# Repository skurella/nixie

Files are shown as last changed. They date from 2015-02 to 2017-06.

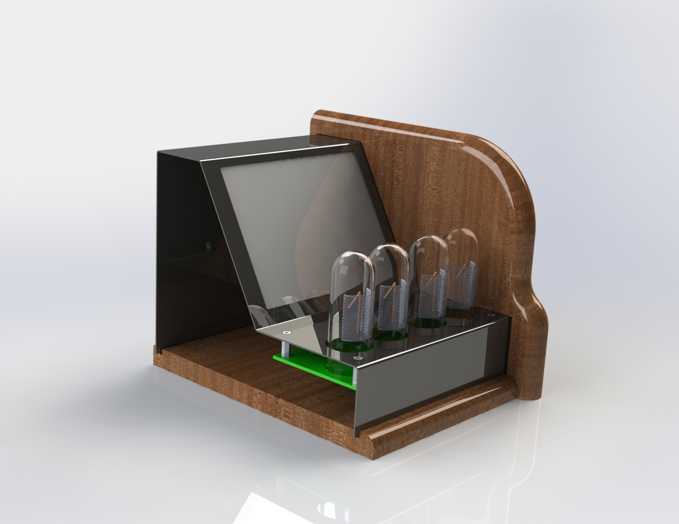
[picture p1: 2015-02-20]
mechanical/housing_render4.JPG

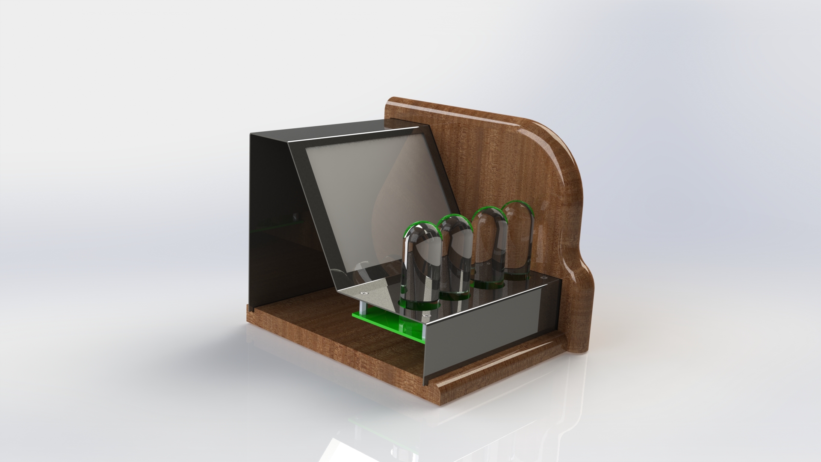
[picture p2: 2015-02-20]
mechanical/housing_render3.JPG

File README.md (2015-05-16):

# nixie
## Nixie tube

Nixie tubes were used extensivaly in 60's and 70's in various instruments to display digits and other symbols. They are cold cathode tubes made of glass with one anode (a grid) and multiple cathodes, each of which is shaped like the displayed sign.

Cold cathode means that the tube is cool during operation (usually does not exceed 40°C). However, it runs on high voltage (around 200V), so do not attempt to build this project if you don't know exactly what you are doing.

## Clock

- features four tubes to display hours and minutes
- has an alarm
- is powered by 12V DC
- easily reprogrammable with a PICkit3
- can communicate via serial
- time is battery backed

## Electronics

- Microchip PIC16F722A/723A microcontroller
- Microchip MCP7940N real-time clock/calendar
- switching HV supply
- multiplexed display: one anode pulled to HV, BCD driver pulls selected cathode to ground

## I/O

### Inputs

- rotary encoder with a momentary switch
- push-button (optional)
- anode voltage trimmer

### Outputs

- 4 nixie tubes with digits 0-9
- two LEDs in the upper left-hand corner
- buzzer connector (12V)

### Serial port

There is an optional 3-pin header with GND, TX and RX available should there be a need for interfacing with other equipment.

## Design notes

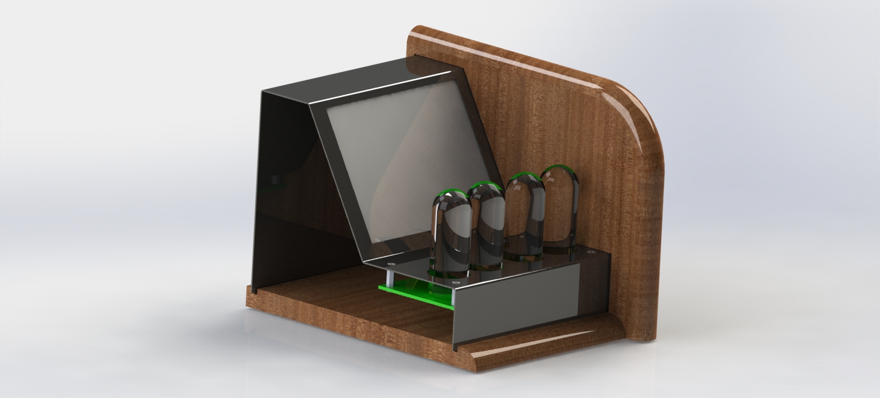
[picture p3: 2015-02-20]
mechanical/housing_render2.JPG

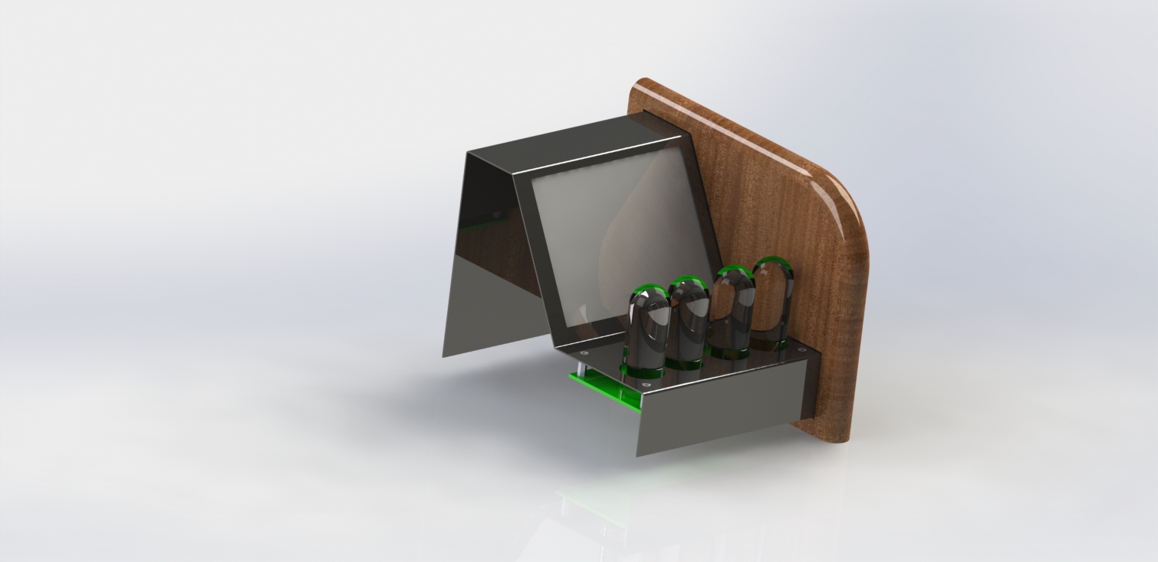
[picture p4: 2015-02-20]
mechanical/housing_render1.JPG

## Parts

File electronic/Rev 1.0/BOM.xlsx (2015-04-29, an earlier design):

Part | Package | Value | On PCB | Manufacturer | Quantity | Farnell | RS | Link | Unit price | Total price
R1-4 | SMD 0805 | 390K | 4 |  | 10 | 2332106 |  | http://uk.farnell.com/te-connectivity/crgh0805f390k/resistor-power-390k-0-33w-1-0805/dp/2332106 | 0.0196 | 0.0784
R5-8 | SMD 0805 | 51K | 4 |  | 10 | 2323854 |  | http://uk.farnell.com/panasonic-electronic-components/erj6geyj513v/resistor-thick-film-51kohm-5-0805/dp/2323854 | 0.009 | 0.036
R9, R11 | SMD 0805 | 10k | 2 |  | 10 | 1612522 |  | http://uk.farnell.com/bourns/cr0805-fx-1002elf/resistor-10k-0-125w-1/dp/1612522 | 0.029 | 0.058
R10 | SMD 0805 | 47k | 1 |  | 10 | 2333525 |  | http://uk.farnell.com/bourns/cr0805-fx-4702elf/resistor-thick-film-47kohm-1-0805/dp/2333525 | 0.0281 | 0.0281
R12, R13 | SMD 0805 | 2k2 | 2 |  | 10 | 2333608 |  | http://uk.farnell.com/bourns/cr0805-jw-222elf/resistor-thick-film-2-2kohm-5/dp/2333608 | 0.0319 | 0.0638
R14 | SMD 0805 | 1k | 1 |  | 10 | 1652936 |  | http://uk.farnell.com/vishay-draloric/crcw08051k00fkta/thick-film-chip-resistor/dp/1652936 | 0.02 | 0.02
R15 | SMD 0805 | 680k | 1 |  | 10 | 2303859 |  | http://uk.farnell.com/panasonic-electronic-components/erj6enf6803v/res-thick-film-680k-125mw-1-0805/dp/2303859 | 0.013 | 0.013
R16 | SMD 0805 | 330R | 1 |  | 10 | 2333593 |  | http://uk.farnell.com/bourns/cr0805-jw-331elf/resistor-thick-film-330-ohm-5/dp/2333593 | 0.0304 | 0.0304
R17 | SMD 0805 | 3k3 | 1 |  | 10 | 2303604 |  | http://uk.farnell.com/panasonic-electronic-components/erj6enf3301v/res-thick-film-3k3-125mw-1-0805/dp/2303604 | 0.016 | 0.016
C1-2 | SMD 0805 | 18pF | 2 |  | 10 | 1759194 |  | http://uk.farnell.com/multicomp/mc0805n180j500ct/cap-mlcc-c0g-np0-18pf-50v-0805/dp/1759194 | 0.0192 | 0.0384
C3-4, 7-8, 10, 13 | SMD 0805 | 100nF | 4 |  | 10 | 2407344 |  | http://uk.farnell.com/vishay/vj0805y104kxacw1bc/cap-mlcc-x7r-0-1uf-50v-0805/dp/2407344 | 0.01 | 0.04
C5-6 | SMD radial 4mm | 10uF | 2 |  | 10 | 2326109 |  | http://uk.farnell.com/panasonic-electronic-components/eee1ca100ar/cap-alu-elec-10uf-16v-smd/dp/2326109 | 0.173 | 0.346
C9 | SMD 0805 | 100pF | 1 |  | 10 | 2210931 |  | http://uk.farnell.com/tdk/cga4c2c0g2a101j060aa/cap-mlcc-c0g-np0-100pf-100v-0805/dp/2210931 | 0.0493 | 0.0493
C11 |  | 1000uF | 1 |  | 5 | 2065974 |  | http://uk.farnell.com/panasonic-electronic-components/eeeft1c102ap/cap-alu-elec-1000uf-16v-smd/dp/2065974 | 0.832 | 0.832
C12 |  | 4.7uF | 1 |  | 3 | 2346642 |  | http://uk.farnell.com/rubycon/400px4r7mefcta8x11-5/cap-alu-elec-4-7uf-400v-rad/dp/2346642 | 0.302 | 0.302
C14 | SMD 0805 | 1nF | 1 |  | 5 | 9695192 |  | http://uk.farnell.com/panasonic-electronic-components/echu1h102gx5/cap-film-pps-1nf-50v-smd/dp/9695192 | 0.333 | 0.333
L1 |  | 330uH | 1 |  | 2 | 2457912 |  | http://uk.farnell.com/coilcraft/rfc1010b-334ke/inductor-power-330uh-1-5a-10/dp/2457912 | 0.46 | 0.46
Q1-4 | SOT23 | MMBTA92 | 4 |  | 10 | 2114881 |  | http://uk.farnell.com/nxp/mmbta92/trans-pnp-300v-100ma-sot23/dp/2114881 | 0.0867 | 0.3468
Q5-8 | SOT23 | MMBTA42 | 4 |  | 10 | 2114871 |  | http://uk.farnell.com/nxp/mmbta42/trans-npn-300v-100ma-sot23/dp/2114871 | 0.0857 | 0.3428
Q9 | TO-220 | IRF840 | 1 |  | 3 |  | 542-9440 | http://uk.rs-online.com/web/p/mosfet-transistors/5429440/ | 1.2 | 1.2
D1 | DO-214AC | Schottky | 1 |  | 10 |  | 670-8817 | http://uk.rs-online.com/web/p/rectifier-schottky-diodes/6708817/ | 0.162 | 0.162
D2 | TO-220 | BYV29-400 | 1 |  | 3 | 1081351 |  | http://uk.farnell.com/nxp/byv29-400/diode-ultrafast-9a/dp/1081351 | 0.707 | 0.707
U1 | SOIC16 | CD4028B | 1 | TI | 2 | 2342417 |  | http://uk.farnell.com/texas-instruments/cd4028bm96/ic-bcd-to-decimal-decoder-soic/dp/2342417 | 0.093 | 0.093
U2-3 | SOIC16 | SN75468 | 2 | TI | 4 | 9593004 |  | http://uk.farnell.com/texas-instruments/sn75468d/transistor-array-75468-soic16/dp/9593004 | 0.422 | 0.844
U4 | SOT23 | LM3840IM3-5.0 | 1 |  | 2 | 1476698 |  | http://uk.farnell.com/taiwan-semiconductor/ts78l05cx-rf/reg-3-terminal-100ma-smd-sot-23/dp/1476698 | 0.365 | 0.365
U5 | SOIC28 | PIC16F722A-I/SO | 1 | TI | 2 | 1814931 |  | http://uk.farnell.com/microchip/pic16f723a-i-so/mcu-8bit-pic16-20mhz-soic-28/dp/1814931 | 0.89 | 0.89
U6 | SOIC8 | MCP7940N-I/SN | 1 | TI | 2 | 2361122 |  | http://uk.farnell.com/microchip/mcp7940n-i-sn/rtcc-gp-i2c-64b-sram-8soic/dp/2361122 | 0.715 | 0.715
U7 | SOIC8 | MC34063ADR | 1 | TI | 3 | 1053582 |  | http://uk.farnell.com/texas-instruments/mc34063ade4/dc-dc-controller-smd-34063-soic8/dp/1053582 | 0.56 | 0.56
BT1 |  | HU2032-LF | 1 | Renata | 2 | 1319749 |  | http://uk.farnell.com/renata/hu2032-lf/holder-battery-tht-cr2032/dp/1319749 | 0.818 | 0.818
P1 | terminal block | 1776275-2 | 1 | TE | 2 | 1098611 |  | http://uk.farnell.com/te-connectivity/1776275-2/terminal-block-wire-to-brd-2pos/dp/1098611 | 0.24 | 0.24
X1 | 3.2mm x 1.5mm | 32.768kHz, 9pF | 1 | Abracon | 2 | 2101346 |  | http://uk.farnell.com/abracon/abs07-32-768khz-9-t/crystal-32-768khz-9pf-smd/dp/2101346 | 1.11 | 1.11
VR1 |  | 2k2 | 1 |  | 2 | 1141662 |  | http://uk.farnell.com/vishay-sfernice/t7yb222mb40/trimmer-2k2/dp/1141662 | 1.17 | 1.17
V1-4 | B13D | LC-531 | 4 | Dolam | N/A |  |  |  |  | 0
EN1 |  | PEC12R-2220F-S0024 | 1 | Bourns | 2 |  | 789-9602 | http://uk.rs-online.com/web/p/mechanical-rotary-encoders/7899602/ | 0.77 | 0.77
 |  |  |  |  |  |  |  |  |  | 13.078

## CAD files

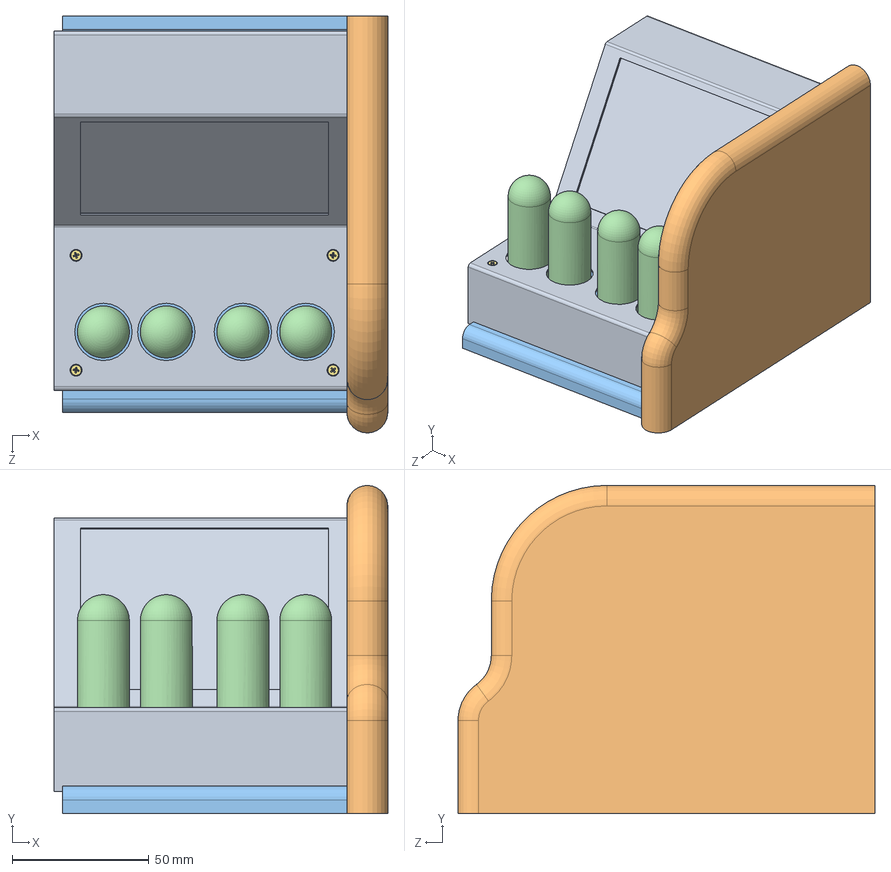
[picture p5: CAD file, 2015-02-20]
mechanical/Housing.SLDASM
122.0 x 120.0 x 152.5 mm
Cover
Right panel
Driver PCB
Nixie tube x 4
Nixie anode x 4
Nixie cathode 1 x 4
flat head screw_am x 4
pan cross head_am x 4
Display
Distance x 4
Bottom panel

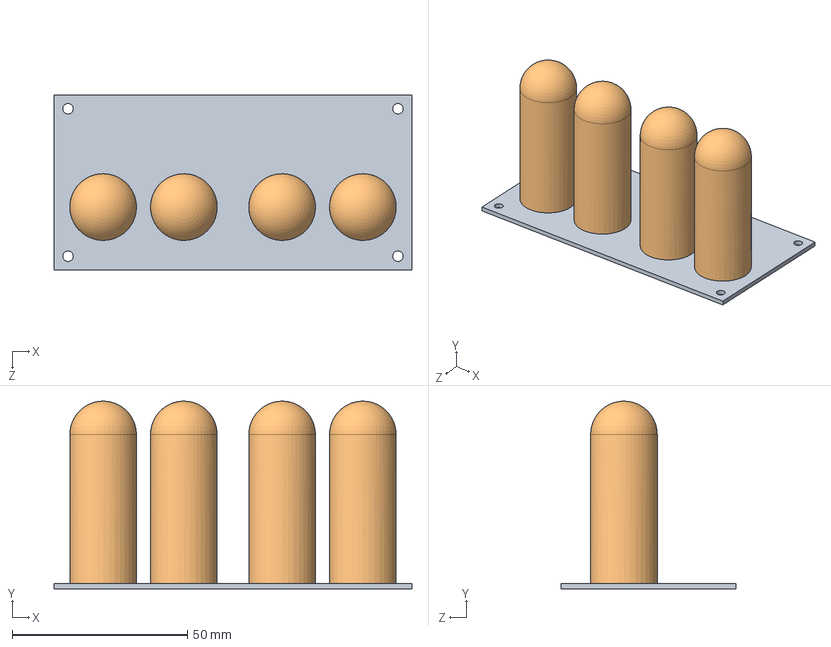
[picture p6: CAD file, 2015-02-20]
mechanical/Driver with tubes.SLDASM
102.0 x 53.5 x 50.0 mm
Driver PCB
Nixie tube x 4
Nixie anode x 4
Nixie cathode 1 x 4

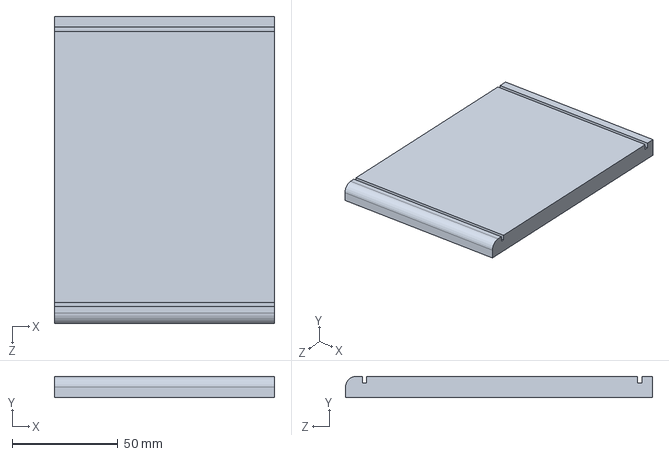
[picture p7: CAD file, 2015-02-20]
mechanical/Bottom panel.SLDPRT
104.0 x 10.0 x 145.0 mm

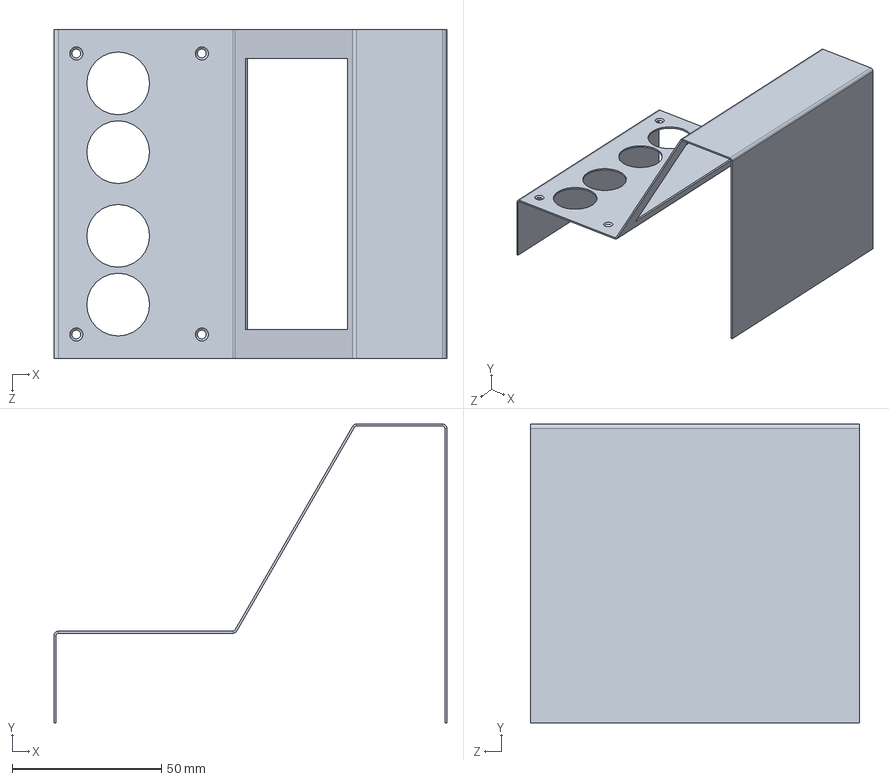
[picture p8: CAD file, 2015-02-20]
mechanical/Cover.sldprt
131.5 x 100.0 x 110.0 mm

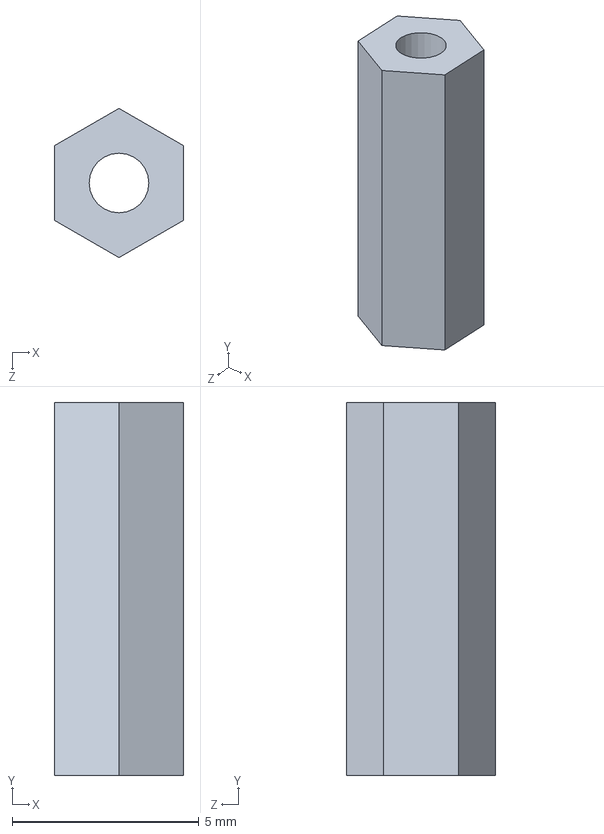
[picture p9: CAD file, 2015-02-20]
mechanical/Distance.SLDPRT
3.46 x 10.0 x 4.00 mm

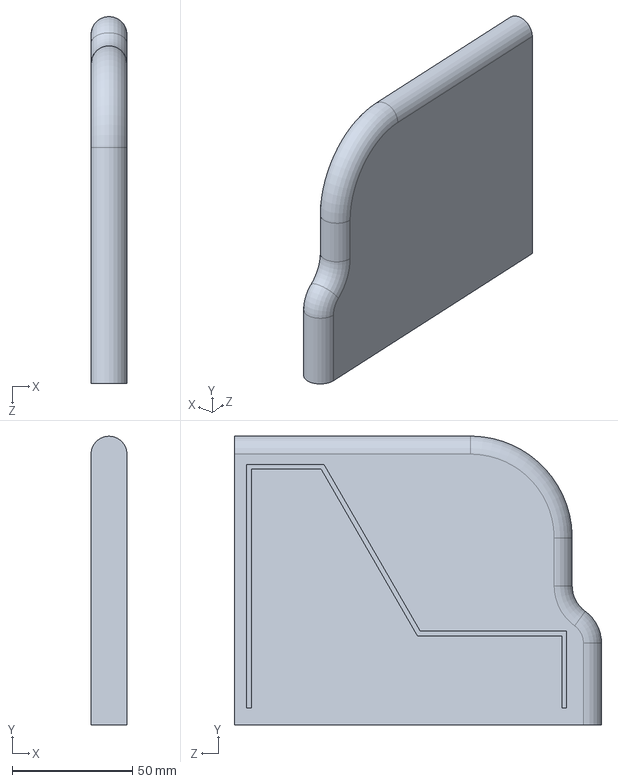
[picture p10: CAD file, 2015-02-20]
mechanical/Right panel.SLDPRT
15.0 x 120.0 x 152.5 mm

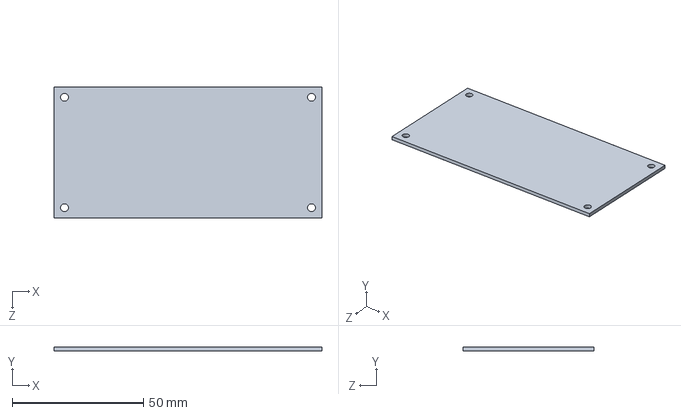
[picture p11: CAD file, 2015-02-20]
mechanical/Driver PCB.SLDPRT
102.0 x 1.50 x 50.0 mm

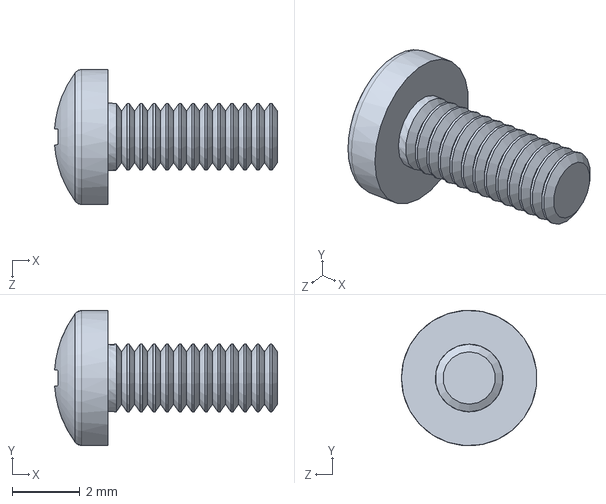
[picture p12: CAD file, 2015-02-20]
mechanical/B18.6.7M - M2 x 0.4 x 5 Type I Cross Recessed PHMS --5S.sldprt
6.58 x 4.00 x 3.99 mm

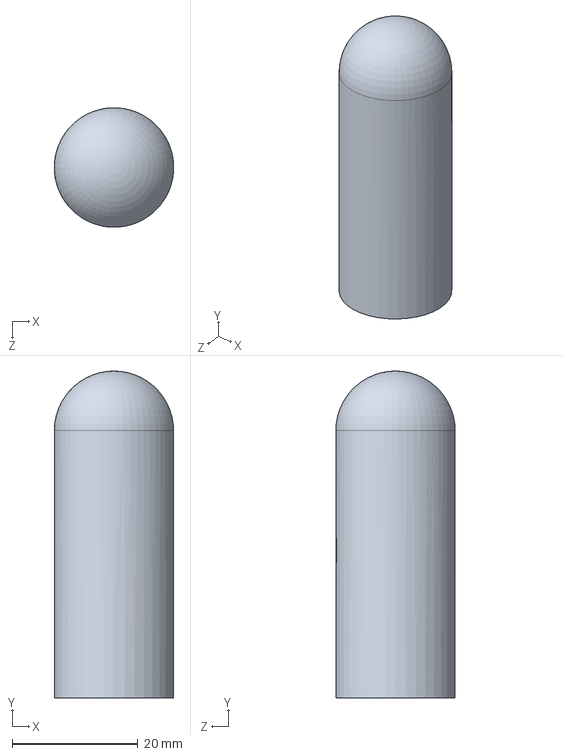
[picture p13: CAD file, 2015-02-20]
mechanical/Nixie tube.SLDPRT
19.0 x 52.0 x 19.0 mm

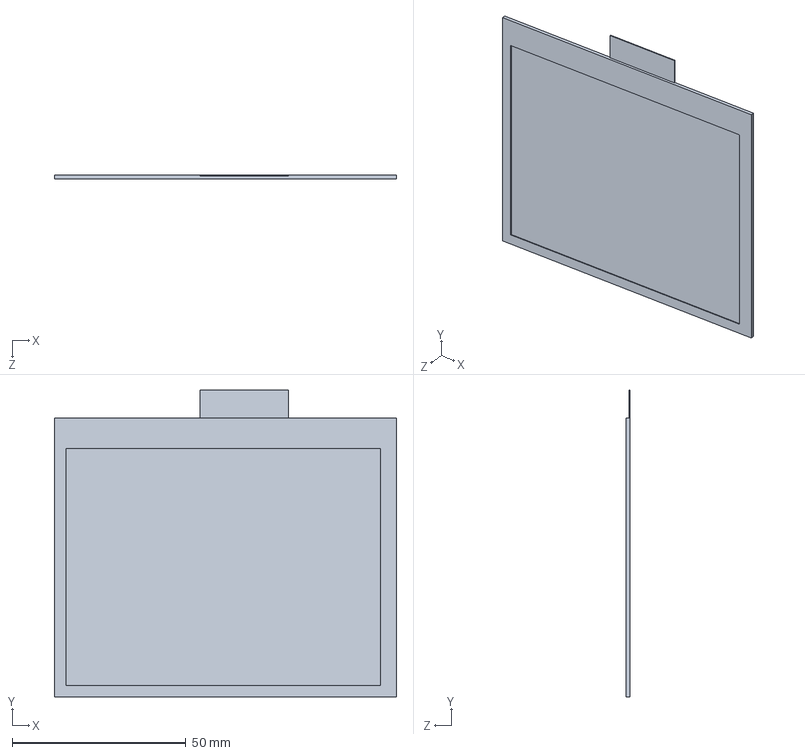
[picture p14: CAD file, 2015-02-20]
mechanical/Display.SLDPRT
98.5 x 88.4 x 1.20 mm

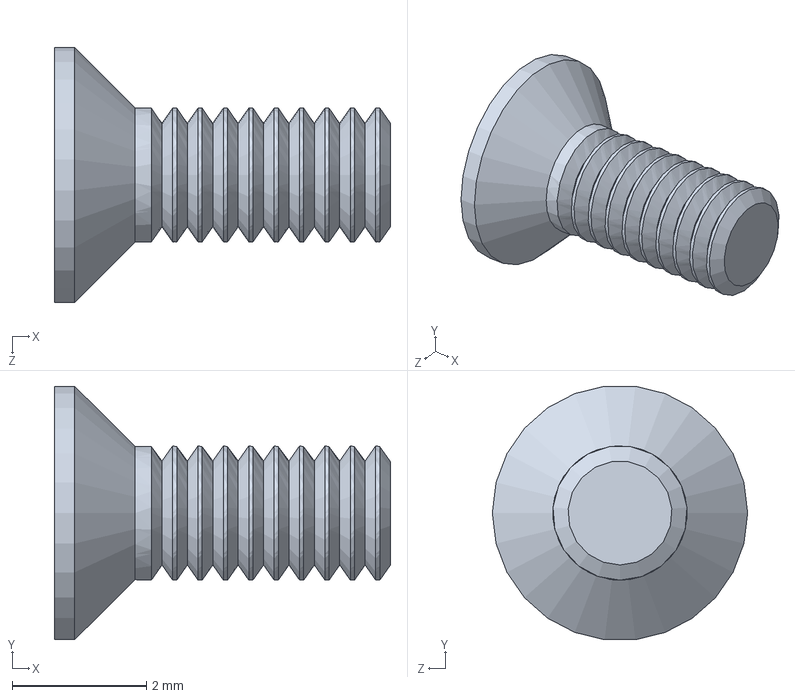
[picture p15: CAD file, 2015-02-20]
mechanical/B18.6.7M - M2 x 0.4 x 5 Type I Cross Recessed FHMS --5S.sldprt
5.00 x 3.77 x 3.80 mm

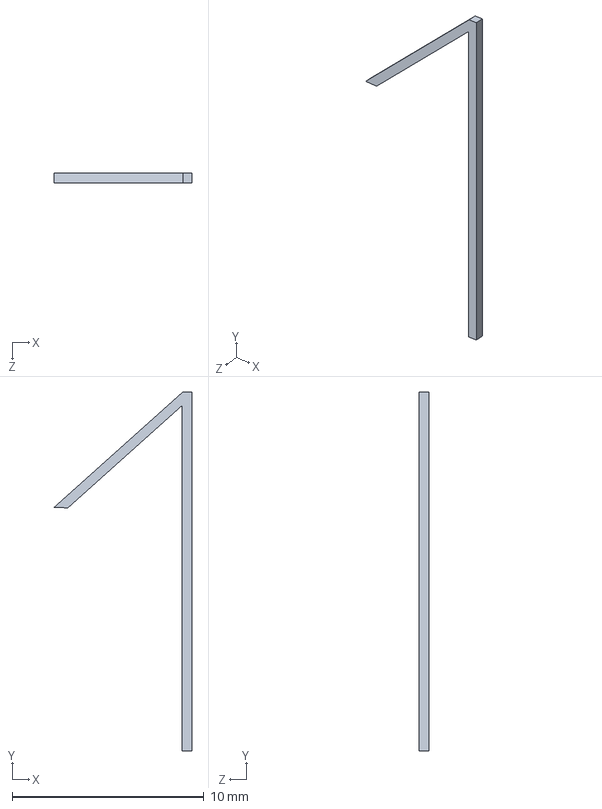
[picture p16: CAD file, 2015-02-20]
mechanical/Nixie cathode 1.SLDPRT
7.17 x 18.7 x 0.5 mm

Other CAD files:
mechanical/Display.SLDDRW

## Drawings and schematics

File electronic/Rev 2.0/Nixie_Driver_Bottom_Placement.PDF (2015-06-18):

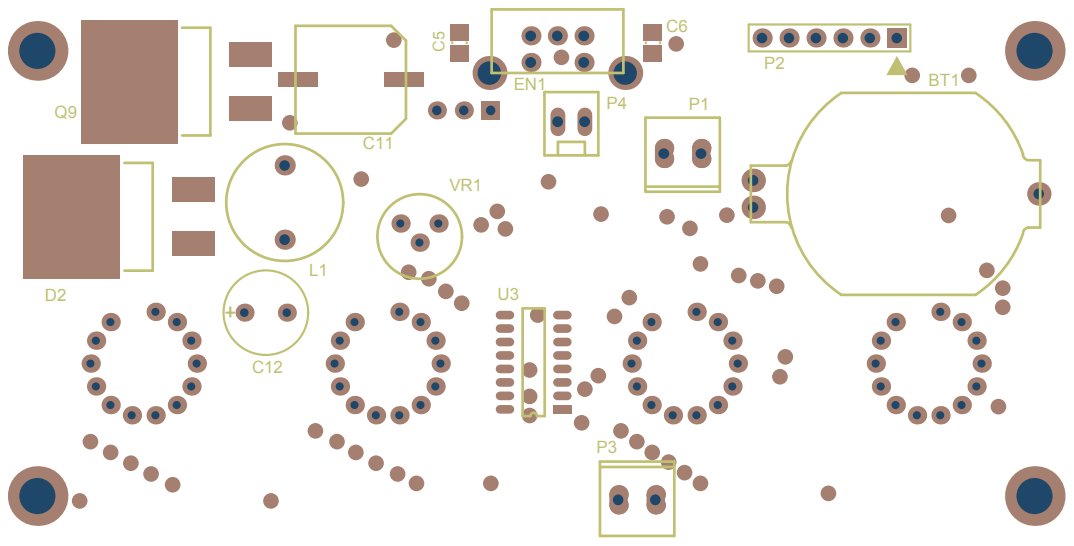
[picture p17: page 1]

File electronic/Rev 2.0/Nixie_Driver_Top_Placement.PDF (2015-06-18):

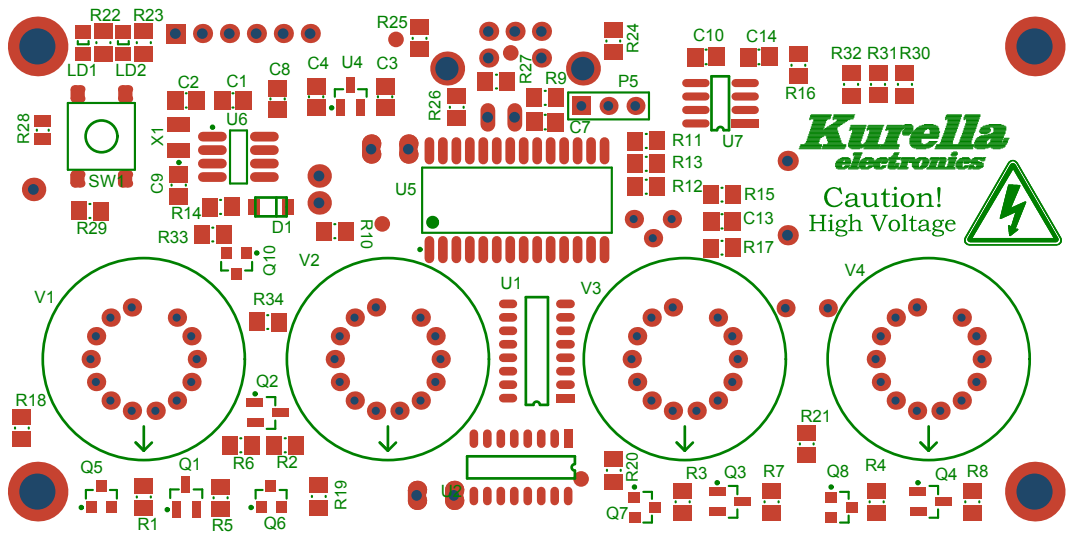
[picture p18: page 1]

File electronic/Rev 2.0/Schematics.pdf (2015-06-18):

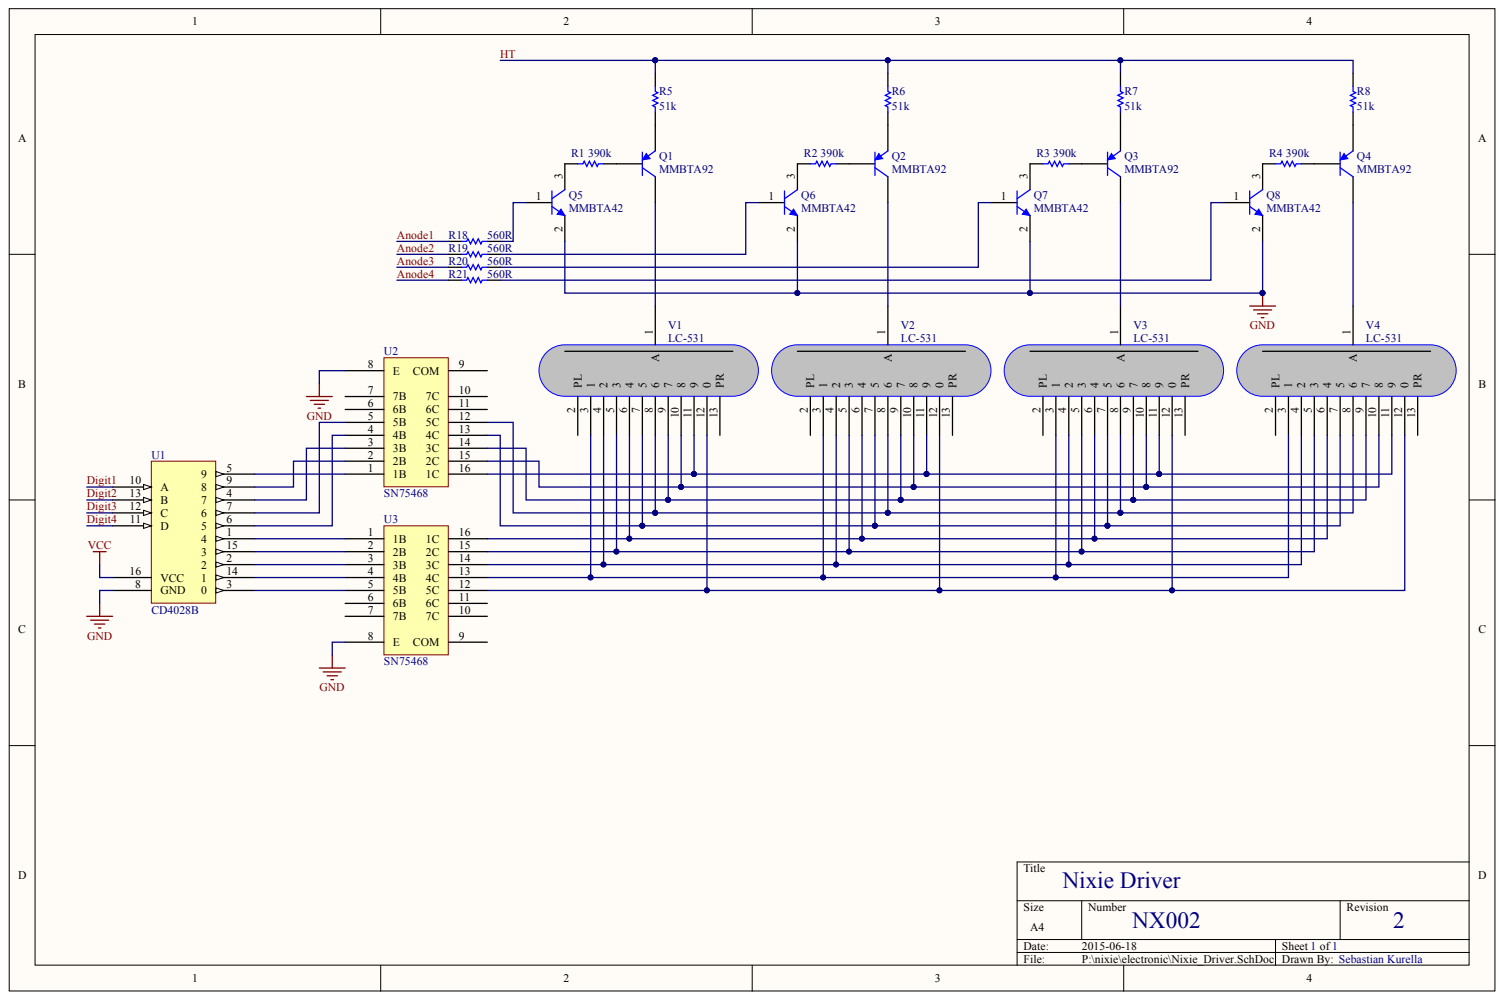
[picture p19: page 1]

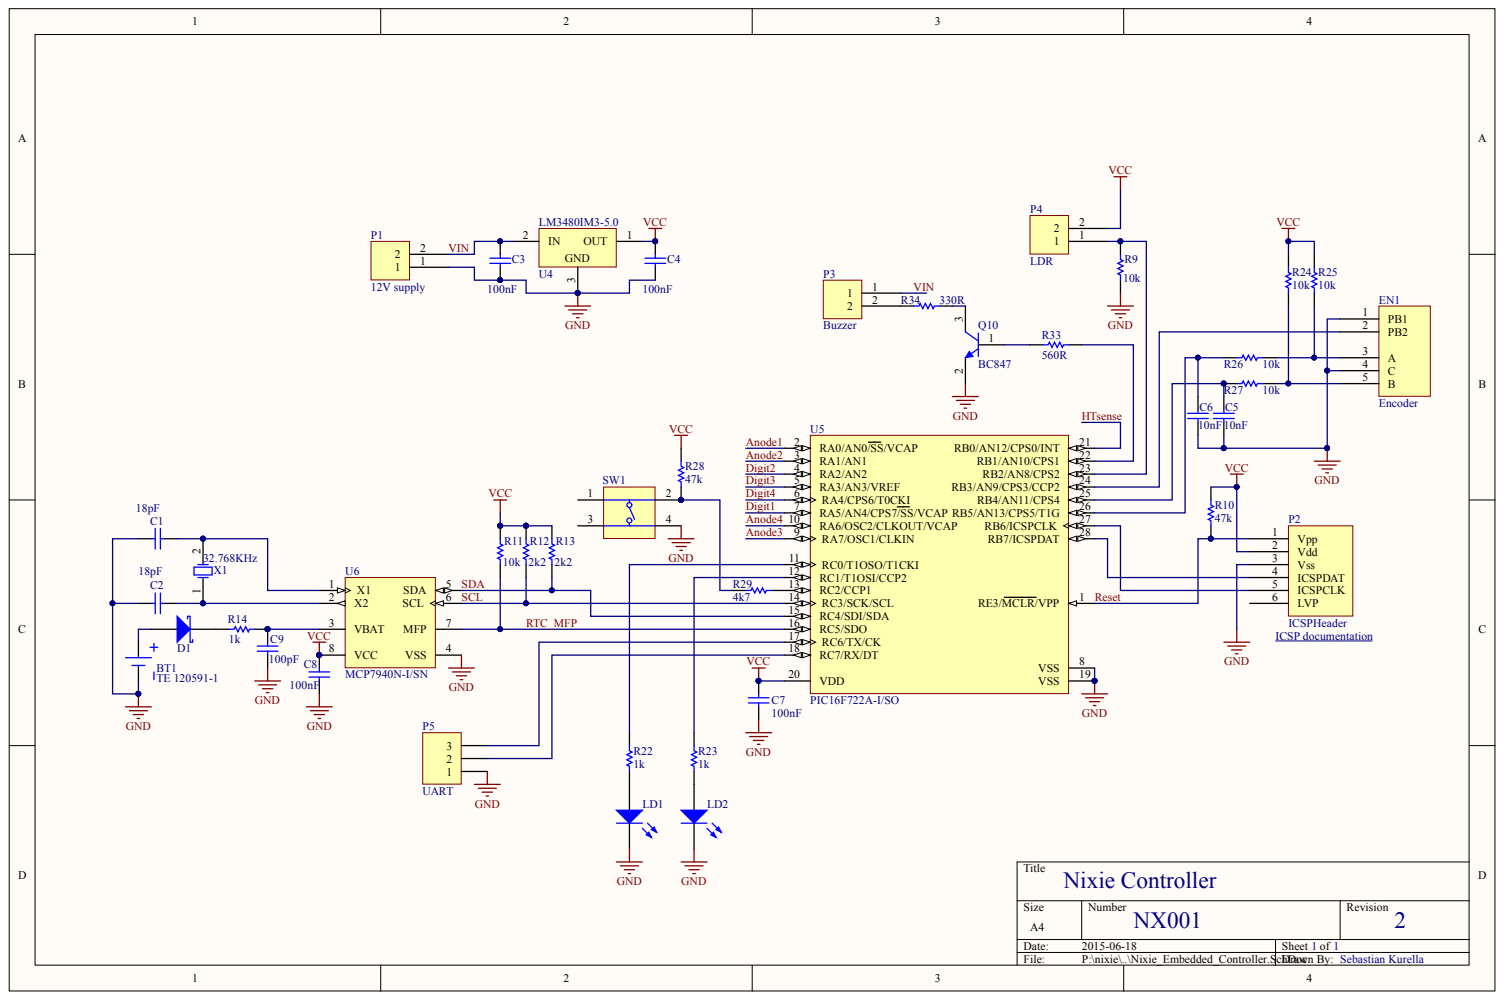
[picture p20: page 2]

2 | 6 | 4k7 | RC3/SCK/SCL 14 | Reset | 6

7 | | RC4/SDI/SDA 15

RTC_MF P | | RC5/SDO 16

RC6/TX/CK 17
RC7/RX/DT 18

VCC

P:\nixie\..\Nixie_Embedded_Controller.SchDoc Drawn By:

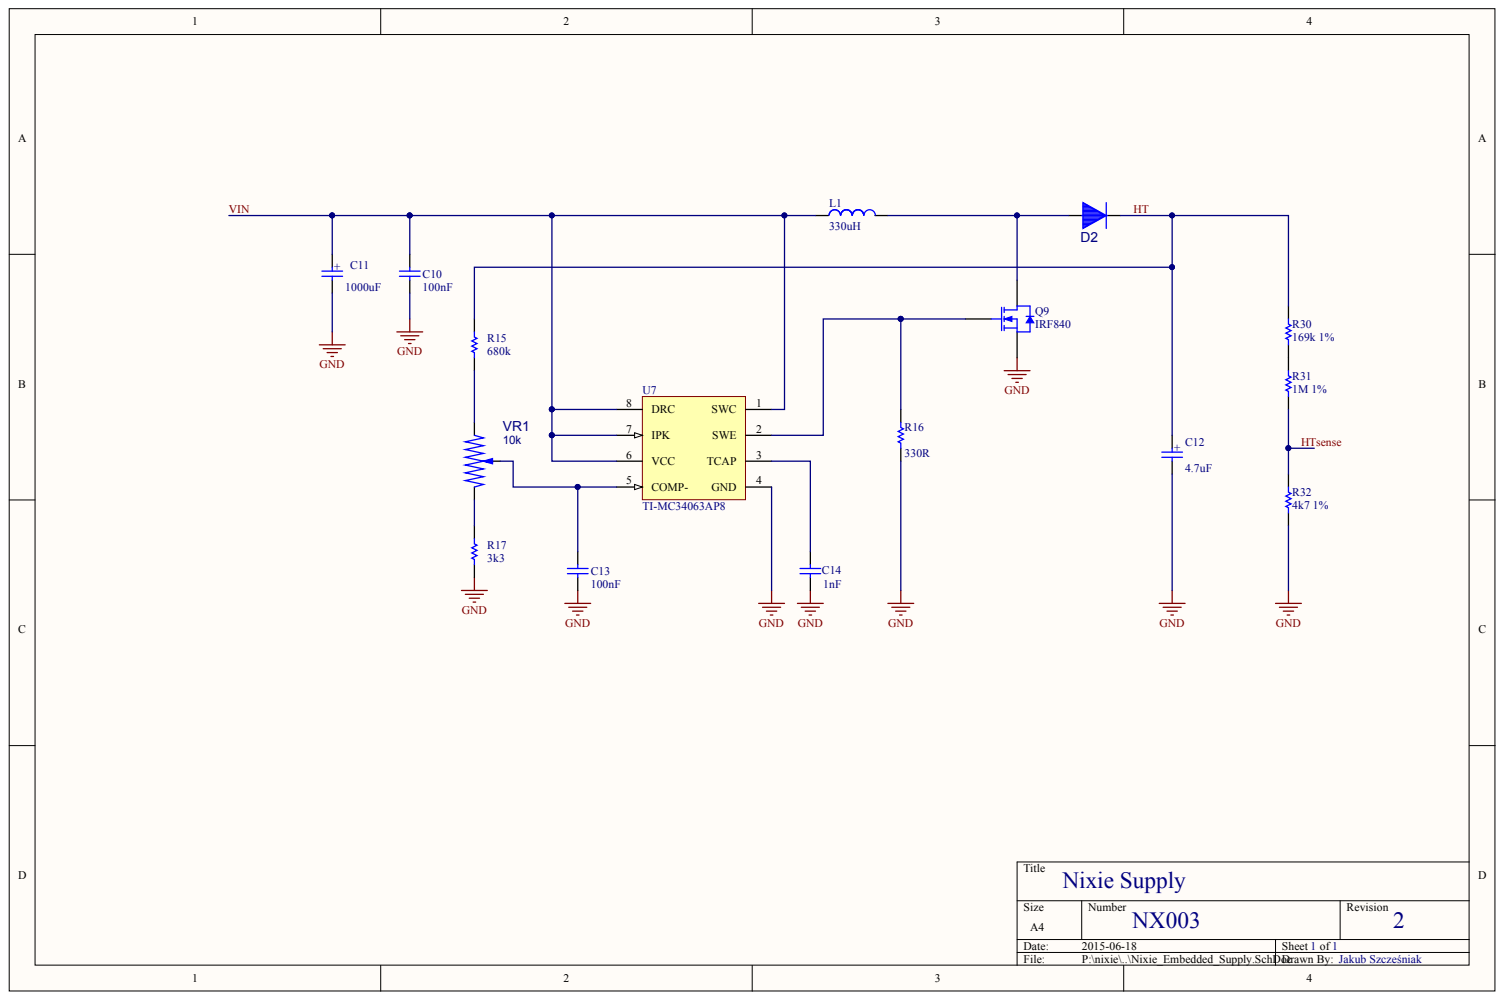
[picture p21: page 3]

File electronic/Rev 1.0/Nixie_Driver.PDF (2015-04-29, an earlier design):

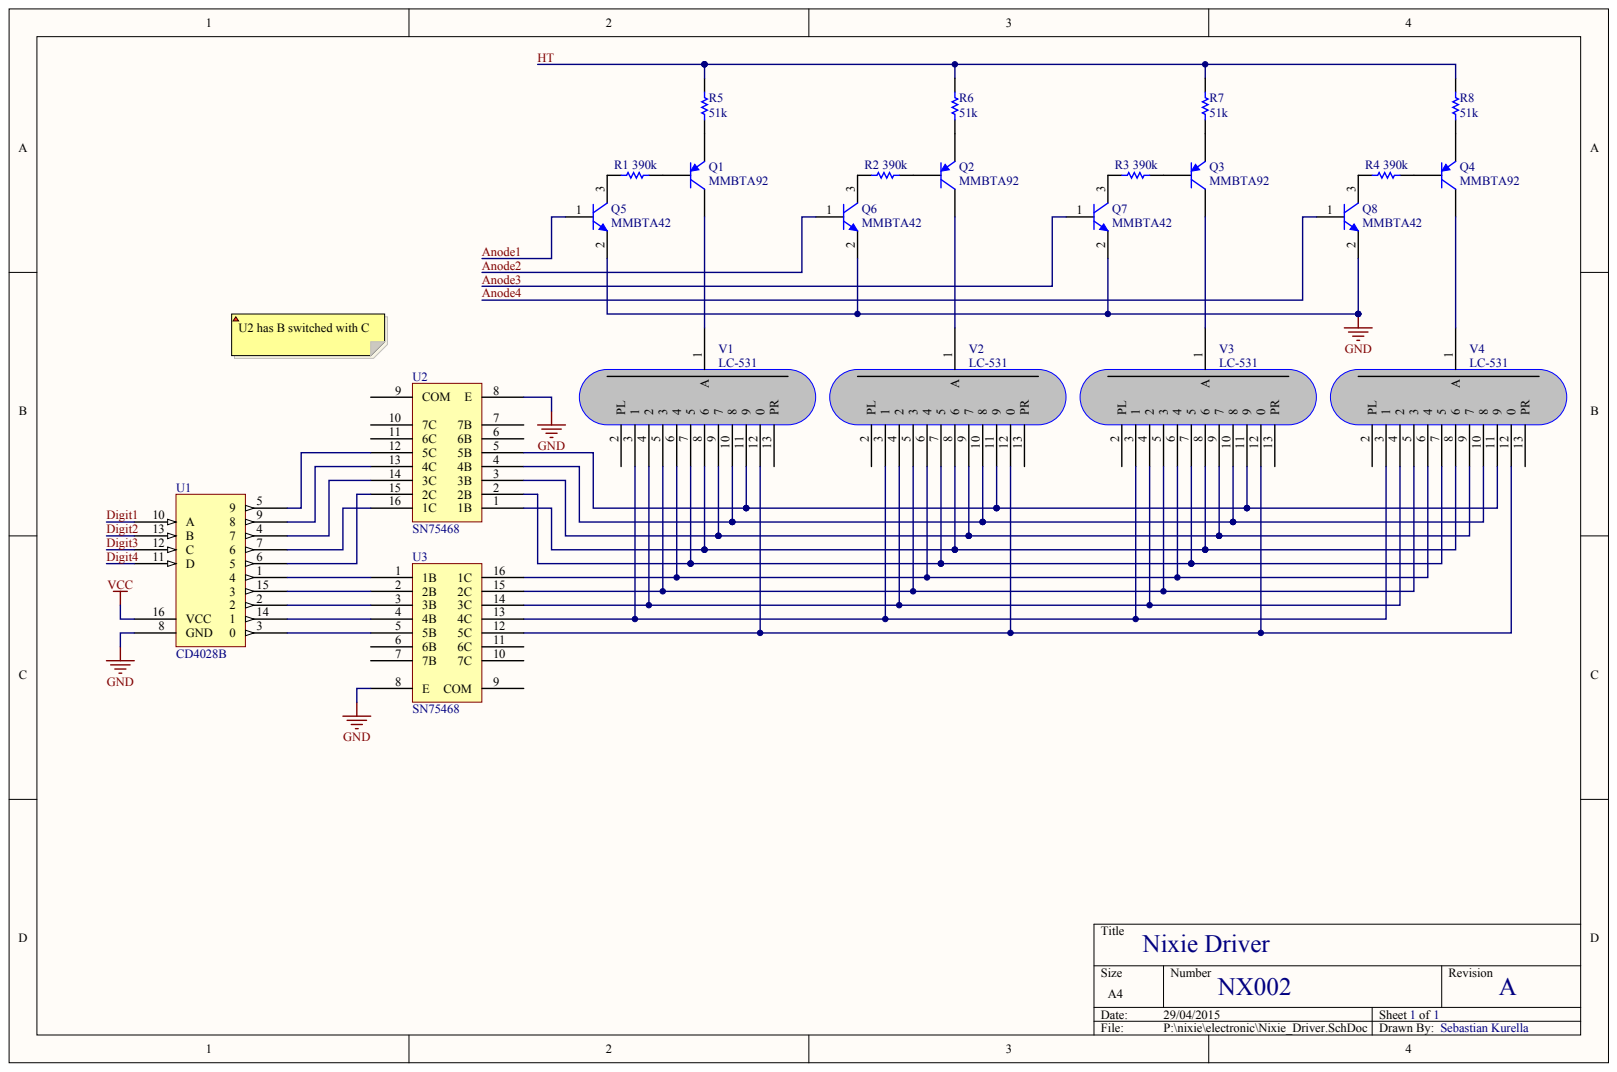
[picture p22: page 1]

Anode3
Anode4

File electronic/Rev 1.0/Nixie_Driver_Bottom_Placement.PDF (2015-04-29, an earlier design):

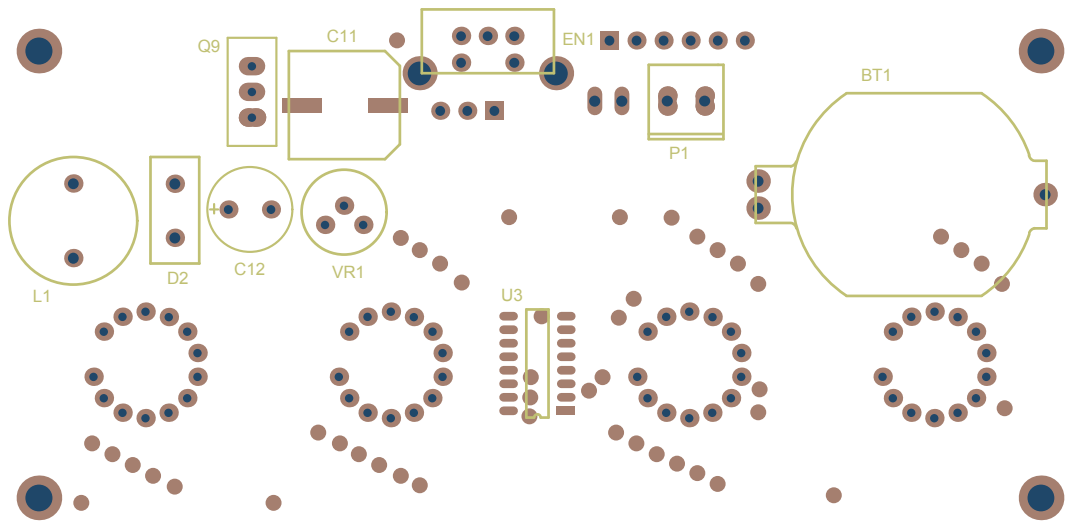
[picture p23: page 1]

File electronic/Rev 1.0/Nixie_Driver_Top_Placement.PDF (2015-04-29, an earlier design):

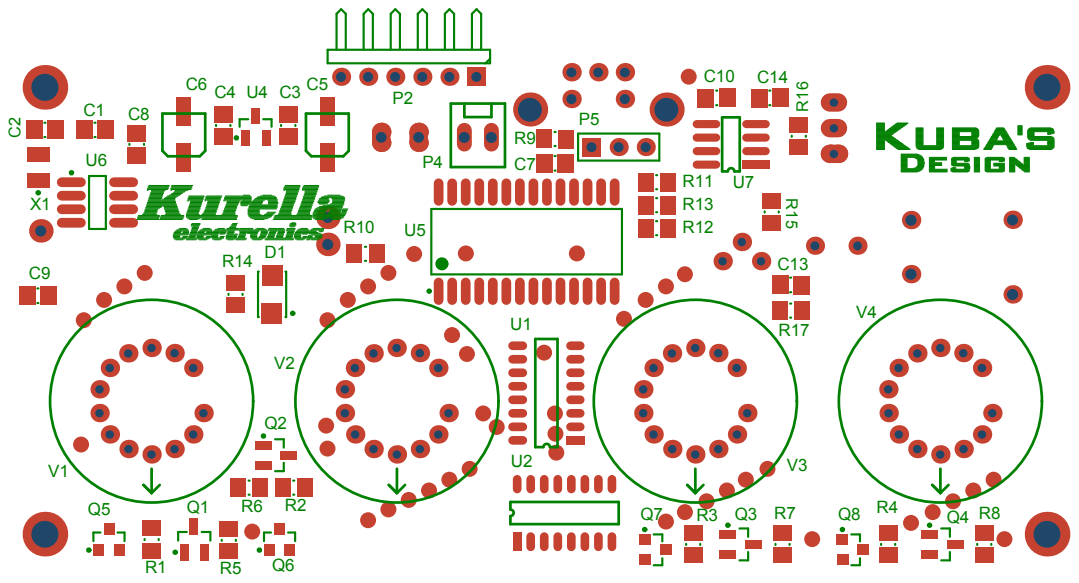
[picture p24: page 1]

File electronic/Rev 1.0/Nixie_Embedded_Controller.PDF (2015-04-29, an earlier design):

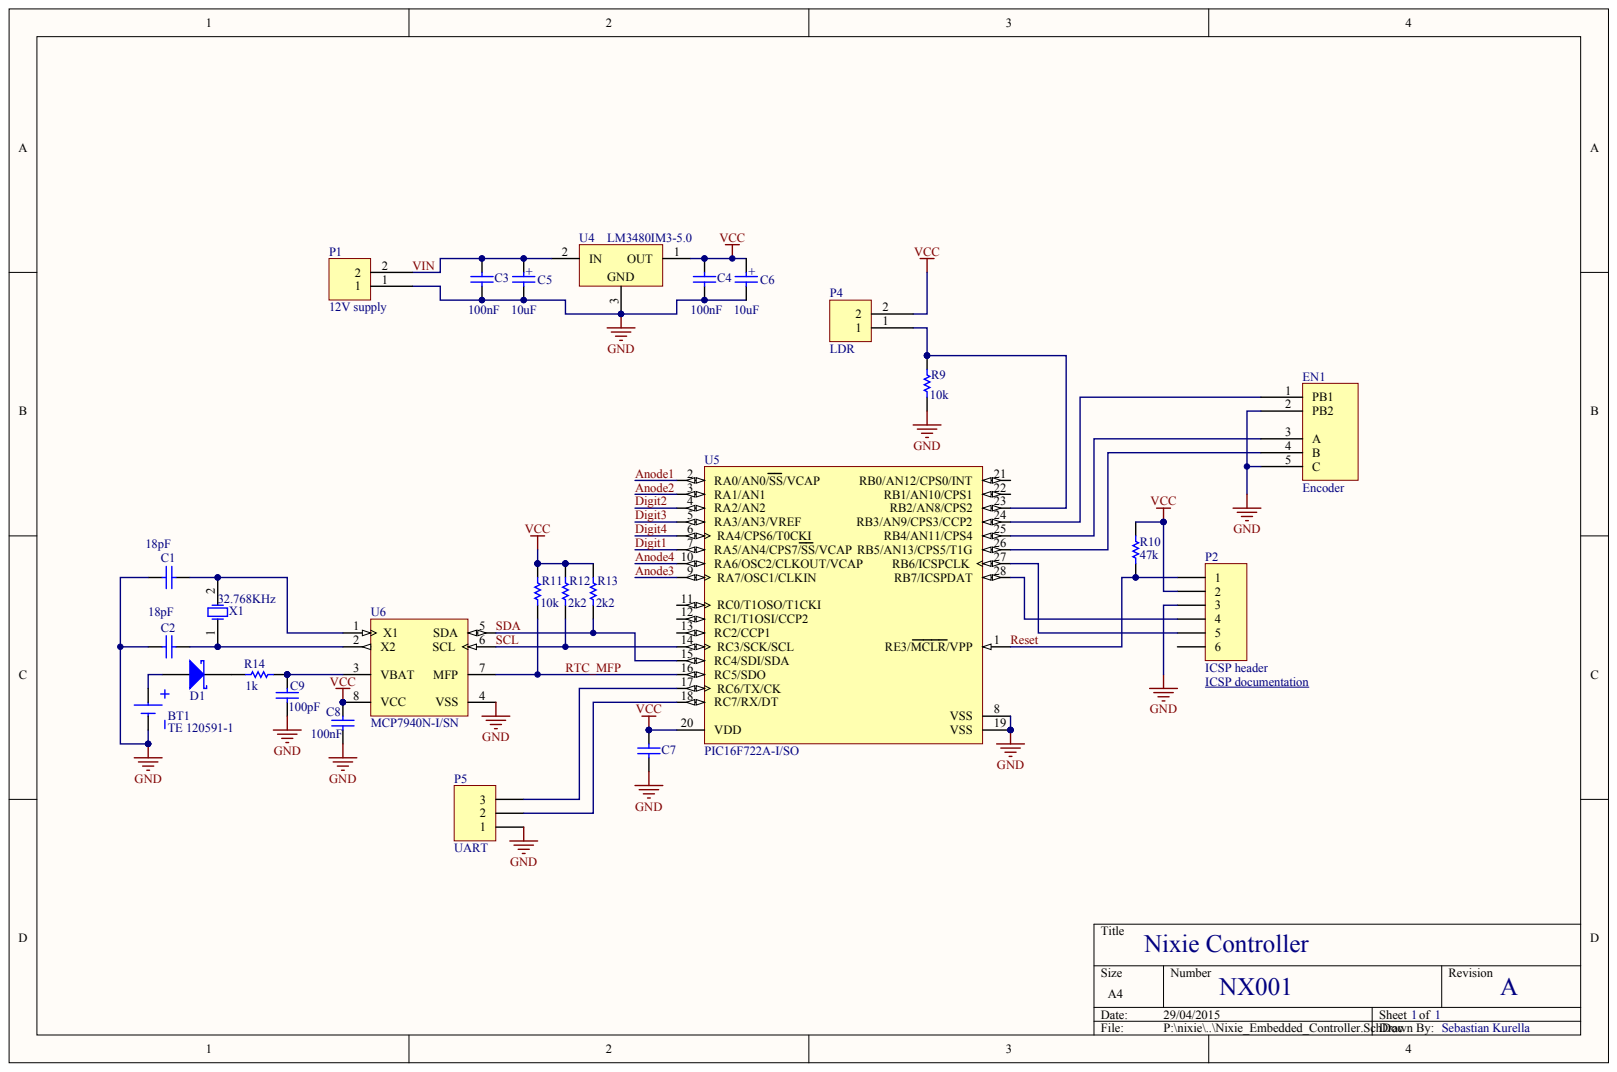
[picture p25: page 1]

2 | 6 | SCL | RC3/SCK/SCL 14 | Reset

7 | | RC4/SDI/SDA 15

VCC

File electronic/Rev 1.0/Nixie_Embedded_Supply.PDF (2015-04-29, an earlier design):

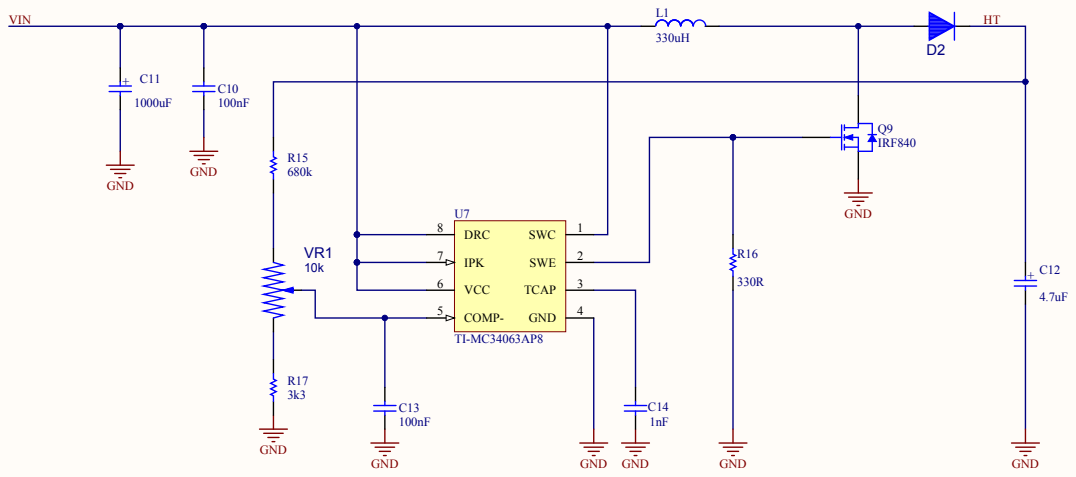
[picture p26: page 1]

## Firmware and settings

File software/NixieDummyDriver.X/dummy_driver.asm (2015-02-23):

;/////////////////////////////////////////////////////;
;/ Nixie tube clock driver dummy - simulates nixies  /;
;/ To be used with University of Manchester IO Board /;
;/ Author: Sebastian Kurella                         /;
;/                                                   /;
;/ PB2 displays hours, PB1 displays minutes          /;
;/ Low nibble of SW1 is simulated 74141 input        /;
;/ High nibble of SW1 is simulated 'tube select'     /;
;/////////////////////////////////////////////////////;



        processor   18F8722
        #include    <P18F8722.INC>
        config      OSC=HS, WDT=OFF, LVP=OFF
        radix       decimal

        CBLOCK	0x80

        HoursT      ; tens digit of current hour
        HoursU      ; units digit of current hour
        MinutesT    ; tens digit of current minute
        MinutesU    ; units digit of current minute

        DispView    ; 0 - hours, 1 - minutes

        LDispValue  ; digit to be displayed on right display
        RDispValue  ; digit to be displayed on right display

        WREG_TEMP	; variables used for context saving
        STATUS_TEMP
        BSR_TEMP

        ENDC

; reset vector - this is the entry point of the program
        ORG     0x0000
        goto    Init

; high priority interrupt vector
        ORG     0x0008
        ; high-p int code goes here
        retfie  FAST

; low priority interrupt vector
        ORG     0x0018
        goto    LowInt



; BCDTable is a lookup table which converts BCD to RF config
; in order to display this digit on 7-segment display

BCDTable    sublw   9           ; check if number is within BCD range
            btfss   STATUS, 0   ; if WREG was > 9, it's invalid
            retlw   B'11111011'
            sublw   9           ; return WREG to original state

            movf    PCL, F      ; update PC registers
            rlncf   WREG, W     ; multiply by 2 to get the correct offset
            addwf   PCL         ; Add offset to force jump into table
            retlw   B'10000100' ; '0'
            retlw   B'11110101' ; '1'
            retlw   B'01001100' ; '2'
            retlw   B'01100100' ; '3'
            retlw   B'00110101' ; '4'
            retlw   B'00100110' ; '5'
            retlw   B'00000110' ; '6'
            retlw   B'11110100' ; '7'
            retlw   B'00000100' ; '8'
            retlw   B'00100100' ; '9'





; initialize the microcontroller

Init    bcf     TRISH, 0        ; set RH0 as output - Q1 transistor
        bcf     TRISH, 1        ; set RH1 as output - Q2 transistor
        bcf     LATH, 0         ; pull RH0 value low - enable U1
        bsf     LATH, 1         ; pull RH1 value high - disable U2

        movlw   B'11111111'     ; set RF output values - all segments off
        movwf   LATF
        movlw   0               ; set RF as output
        movwf   TRISF

        bsf     TRISJ, 5        ; set RJ5 as input - PB1
        bsf     TRISB, 0        ; set RB0 as input - PB2

        movlw   B'00111100'     ; set RC2,3,4,5 as inputs - SW1H
        iorwf   TRISC
        movlw   B'11110000'     ; set RH4,5,6,7 as inputs - SW1L
        iorwf   TRISH
        movlw   B'00000011'     ; set RH4-7 as digital I/O
        iorwf   ADCON1

; set up initial time value
        movlw   1
        movwf   HoursT
        movlw   2
        movwf   HoursU
        movlw   3
        movwf   MinutesT
        movlw   4
        movwf   MinutesU

; initially display hours
        CALL    DispH

; set up Timer0
; display switch frequency: (10 Mhz / 4) / 64 / 2^8 = 152.6 Hz
        movlw   B'01000101'     ; Timer off, 8bit, internal clock, prescaler 1:64
        movwf   T0CON
        bsf     INTCON, TMR0IE  ; Enable overflow interrupt
        bcf     INTCON2, TMR0IP ; Low interrupt priority

        bsf     RCON, IPEN      ; Enable interrupt priority
        bsf     INTCON, GIE     ; Enable high-priority interrupts
        bsf     INTCON, PEIE    ; Enable low-priority interrupts
        bsf     T0CON, TMR0ON   ; Start Timer0


; main loop
; continuously monitor push-buttons and toggle switches

MLoop
        btfss   PORTB, 0        ; show hours if PB2 is pressed
        CALL    DispH
        btfss   PORTJ, 5        ; show minures if PB1 is pressed
        CALL    DispM

        movf    PORTH, W        ; read SW1H
        andlw   B'11110000'
        bz MLoop                ; return if none is selected

        rrncf   PORTC, W        ; read SW1L value
        rrncf   WREG
        andlw   B'00001111'

        btfsc   PORTH, 7        ; set tens of hours if SW1a is on
        movwf   HoursT
        btfsc   PORTH, 6        ; set units of hours if SW1b is on
        movwf   HoursU
        btfsc   PORTH, 5        ; set tens of minutes if SW1c is on
        movwf   MinutesT
        btfsc   PORTH, 4        ; set units of minutes if SW1d is on
        movwf   MinutesU

        CALL    DRefr

        bra     MLoop           ; execute main loop forever




; low priority interrupt saves and restores working registers
; because FAST stack is used by high priority interrupts

LowInt  movff   STATUS, STATUS_TEMP	;save STATUS register
        movff   WREG, WREG_TEMP		;save working register
        movff   BSR, BSR_TEMP		;save BSR register

        btfss   INTCON, TMR0IF      ; branch if Timer0 not OV
        bra     LIntRet

        bcf     INTCON, TMR0IF      ; clear Timer0 overflow flag

        btg     LATH, 0             ; toggle Q1 - switch U1 on or off
        btg     LATH, 1             ; toggle Q2 - switch U2 on or off
        btfss   LATH, 0             ; check which display is to be switched on
        bra     RDisp

        ; handle left display
        movff   LDispValue, LATF
        bra     LIntRet

        ; handle right display
RDisp   movff   RDispValue, LATF

LIntRet movff   BSR_TEMP, BSR		;restore BSR register
        movff	WREG_TEMP, WREG		;restore working register
        movff	STATUS_TEMP, STATUS	;restore STATUS register

        retfie


; this subroutine refreshes the displayed values
DRefr   btfss   DispView, 0
        CALL    DispH
        btfsc   DispView, 0
        CALL    DispM
        return

; this subroutine places Hours [BCD] in DispValue registers [7seg]
DispH   movf    HoursT, W       ; convert BCD to 7seg
        CALL    BCDTable
        movwf   LDispValue      ; place tens in left display
        movf    HoursU, W
        CALL    BCDTable
        movwf   RDispValue      ; place units in right display
        bcf     DispView, 0     ; set hours view
        return

; this subroutine places Minutes [BCD] in DispValue registers [7seg]
DispM   movf    MinutesT, W       ; convert BCD to 7seg
        CALL    BCDTable
        movwf   LDispValue      ; place tens in left display
        movf    MinutesU, W
        CALL    BCDTable
        movwf   RDispValue      ; place units in right display
        bsf     DispView, 0     ; set minutes view
        return


        END

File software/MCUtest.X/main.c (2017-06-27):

/* 
 * File:   main.c
 * Author: Sebastian Kurella
 *
 * Created on 22.05.2015, 16:42
 */

#include "peripherals.h"


// PIC16F1518 Configuration Bit Settings

// 'C' source line config statements

#include <xc.h>

// #pragma config statements should precede project file includes.
// Use project enums instead of #define for ON and OFF.

// CONFIG1
#pragma config FOSC = INTOSC    // Oscillator Selection (INTOSC oscillator: I/O function on CLKIN pin)
#pragma config WDTE = OFF       // Watchdog Timer Enable (WDT disabled)
#pragma config PWRTE = OFF      // Power-up Timer Enable (PWRT disabled)
#pragma config MCLRE = ON       // MCLR Pin Function Select (MCLR/VPP pin function is MCLR)
#pragma config CP = OFF         // Flash Program Memory Code Protection (Program memory code protection is disabled)
#pragma config BOREN = OFF      // Brown-out Reset Enable (Brown-out Reset disabled)
#pragma config CLKOUTEN = OFF   // Clock Out Enable (CLKOUT function is disabled. I/O or oscillator function on the CLKOUT pin)
#pragma config IESO = OFF       // Internal/External Switchover (Internal/External Switchover mode is disabled)
#pragma config FCMEN = ON       // Fail-Safe Clock Monitor Enable (Fail-Safe Clock Monitor is enabled)

// CONFIG2
#pragma config WRT = OFF        // Flash Memory Self-Write Protection (Write protection off)
#pragma config VCAPEN = OFF     // Voltage Regulator Capacitor Enable bit (VCAP pin function disabled)
#pragma config STVREN = ON      // Stack Overflow/Underflow Reset Enable (Stack Overflow or Underflow will cause a Reset)
#pragma config BORV = LO        // Brown-out Reset Voltage Selection (Brown-out Reset Voltage (Vbor), low trip point selected.)
#pragma config LPBOR = OFF      // Low-Power Brown Out Reset (Low-Power BOR is disabled)
#pragma config LVP = OFF        // Low-Voltage Programming Enable (High-voltage on MCLR/VPP must be used for programming)


#define _XTAL_FREQ  1000000

#include <stdio.h>
#include <stdlib.h>

#include "nixie.h"
#include "i2c.h"
#include "encoder.h"

#define CLOCK_STATE_IDLE    0   // display the time
#define CLOCK_STATE_SETHOUR 1   // set hours of the time
#define CLOCK_STATE_SETMIN  2   // set minutes of the time
#define CLOCK_STATE_ALARM   3   // sound the alarm
#define CLOCK_STATE_ALMHOUR 4   // set hours of alarm
#define CLOCK_STATE_ALMMIN  5   // set minutes of alarm
#define CLOCK_STATE_CAL     6   // calibrate the clock
#define CLOCK_STATE_VOLTAGE 7   // display HT voltage

volatile char clock_state = CLOCK_STATE_IDLE;

volatile unsigned int ui_timer = 0;

char encoder_pressed = 0;
char button_pressed = 0;

char hour = 0, min = 0; // raw BCD data read directly from RTC
char sethour, setmin;   // values of mins and hours used for setting time
char showhour, showmin; // to aid blinking during setting the time

void interrupt tc_int() {
    while (1) {
        if (TMR0IE && TMR0IF) {
            TMR0IF = 0;
            ++current_tube;
            current_tube %= 4;

            PORTA = display[current_tube];
            continue;
        }

        if (TMR2IE && TMR2IF) {
            TMR2IF = 0;
            ++ui_timer;
            if (ui_timer == 6000) { // count max to one minute
                ui_timer = 0;
            }

            continue;
        }
        
        return;
    }
}

void Timer2_init() {
    // Initialize Timer2
    // Prescaler 1:4, postscaler 1:2
    // Refresh frequency 400Hz when counting to 250
    // (1 Mhz / 1) / (250 * 10 * 4) = 100 Hz

    T2CONbits.T2CKPS = 0b00;    // prescaler
    T2CONbits.T2OUTPS = 10;      // postscaler

    TMR2IF = 0;
    TMR2IE = 1;
    PEIE = 1;
    PR2 = 250;
    TMR2ON = 1;
}

void switch_state(char state) {
    // Switch state
    clock_state = state;

    // Reset the UI timer
    ui_timer = 0;

    // Some states need initialization

    // TODO: red LED when setting time, blue when setting alarm

    switch (state) {
        case CLOCK_STATE_IDLE:
            red_led_off();
            blue_led_off();
            break;
        case CLOCK_STATE_SETHOUR:
            red_led_on();
            blue_led_off();
            break;
        case CLOCK_STATE_ALMHOUR:
            red_led_off();
            blue_led_on();
            break;
    }
    switch (state) {
        case CLOCK_STATE_SETHOUR:
        case CLOCK_STATE_ALMHOUR:
            // Save hour to sethour and minute to setmin
            sethour = 10 * ((hour & 0x70) >> 4);
            sethour += hour & 0x0F;
            setmin = 10 * ((min & 0x70) >> 4);
            setmin += min & 0x0F;
            break;
    }
}

void display_set_time(char hours, char mins) {
    if (hours) {
        nixie_display(0, sethour / 10);
        nixie_display(1, sethour % 10);
    } else {
        nixie_display(0, 10);
        nixie_display(1, 10);
    }

    if (mins) {
        nixie_display(2, setmin / 10);
        nixie_display(3, setmin % 10);
    } else {
        nixie_display(2, 10);
        nixie_display(3, 10);
    }

}

int main() {
    // Set internal oscillator to 1 Mhz
    OSCCONbits.IRCF = 0b1011;

    peripherals_init();

    nixie_init();

    encoder_init();

    i2c_init();
    rtc_start();
    rtc_vbat_enable();

    // Clear the display
    nixie_clear();

    // Start asynchronous timer
    Timer2_init();
    
    // Enable interrupts
    ei();

    // Main loop
    while (1) {

        // TODO: return to idle if user is inactive for 1 minute

        switch (clock_state) {
            case CLOCK_STATE_IDLE:
                // TODO: check HT voltage for changes
                // If encoder switch gets pressed
                if (encoder_button_state() && !encoder_pressed) {
                    encoder_pressed = 1;
                    ui_timer = 0;
                    __delay_ms(5);
                }
                // If encoder switch gets depressed ;_;
                if (!encoder_button_state() && encoder_pressed) {
                    encoder_pressed = 0;
                    __delay_ms(5);
                    if (ui_timer > 100) {
                        switch_state(CLOCK_STATE_SETHOUR);
                        break;
                    } else {
                        switch_state(CLOCK_STATE_ALMHOUR);
                        break;
                    }
                }
                hour = rtc_get_hour();
                nixie_display(0, (hour & 0x70) >> 4);
                nixie_display(1, hour & 0x0F);
                min = rtc_get_min();
                nixie_display(2, (min & 0x70) >> 4);
                nixie_display(3, min & 0x0F);
                break;

            case CLOCK_STATE_SETHOUR:
                if (encoder_button_state() && !encoder_pressed) {
                    encoder_pressed = 1;
                    __delay_ms(5);
                }
                if (!encoder_button_state() && encoder_pressed) {
                    encoder_pressed = 0;
                    __delay_ms(5);
                    switch_state(CLOCK_STATE_SETMIN);
                }
                char state = encoder_updateState();
                if (state == ENCODER_TURN_CLOCKWISE)
                {
                    sethour = (sethour + 59) % 60;
                    display_set_time(showhour, 1);
                }
                if (state == ENCODER_TURN_COUNTERCLOCKWISE)
                {
                    sethour = (sethour + 1) % 60;
                    display_set_time(showhour, 1);
                }
                // TODO: call display_set_time every time
                char newshowhour = ui_timer % 100 < 70;
                if (newshowhour != showhour) {
                    showhour = newshowhour;
                    display_set_time(showhour, 1);
                }
                break;
                
            case CLOCK_STATE_SETMIN:
                if (encoder_button_state() && !encoder_pressed) {
                    encoder_pressed = 1;
                    __delay_ms(5);
                }
                if (!encoder_button_state() && encoder_pressed) {
                    encoder_pressed = 0;
                    __delay_ms(5);
                    hour =
                        (((sethour / 10) & 0xf) << 4) |
                        ((sethour % 10) & 0xf);
                    min =
                        (((setmin / 10) & 0xf) << 4) |
                        ((setmin % 10) & 0xf);
                    rtc_set_hour(hour);
                    rtc_set_min(min);
                    switch_state(CLOCK_STATE_IDLE);
                }
                char state = encoder_updateState();
                if (state == ENCODER_TURN_CLOCKWISE)
                {
                    setmin = (setmin + 59) % 60;
                    display_set_time(1, showmin);
                }
                if (state == ENCODER_TURN_COUNTERCLOCKWISE)
                {
                    setmin = (setmin + 1) % 60;
                    display_set_time(1, showmin);
                }
                // TODO: call display_set_time every time
                char newshowmin = ui_timer % 100 < 70;
                if (newshowmin != showmin) {
                    showmin = newshowmin;
                    display_set_time(1, showmin);
                }
                break;
                
            case CLOCK_STATE_ALARM:
                // TODO
                break;
            case CLOCK_STATE_ALMHOUR:
                // TODO
                break;
            case CLOCK_STATE_ALMMIN:
                // TODO
                break;
            case CLOCK_STATE_CAL:
                // TODO
                break;
            case CLOCK_STATE_VOLTAGE:
                // TODO
                break;
        }
        
    }

    //bulka
    red_led_on();
    __delay_ms(10000);

    return (EXIT_SUCCESS);
}

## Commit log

2015-02-20 Add mechanical models of existing components
    [B18.6.7M - M2 x 0.4 x 5 Type I Cross Recessed FHMS --5S.sldprt, B18.6.7M - M2 x 0.4 x 5 Type I Cross Recessed PHMS --5S.sldprt, Display.SLDDRW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]
2015-02-20 Create mechanical driver dummy PCB
    [Driver PCB.SLDPRT, Driver with tubes.SLDASM]
2015-02-20 Create initial enclosure design
    [Bottom panel.SLDPRT, Cover.sldprt, Distance.SLDPRT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]
2015-02-20 Create controller PCB
    [Nixie_Controller.PrjPcb, Nixie_Controller.SchDoc]
2015-02-20 Controller: add driver header, add LDR
    [Nixie_Controller.PrjPcb, Nixie_Controller.SchDoc, Nixie_Controller.SchLib]
2015-02-21 Add initial Timer0 display handler
2015-02-22 Change display mux interrupt priority to low
2015-02-22 Disable FAST stack for low-p interrupts
2015-02-22 Add hours and minutes switched by push-buttons
2015-02-25 Finish schematic, add PCB
    [Nixie_Controller.PcbDoc, Nixie_Controller.PcbLib, Nixie_Controller.PrjPcb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]
2015-02-26 Finish controller PCB
    [Nixie_Controller.PcbDoc, Nixie_Controller.PrjPcb]
2015-02-26 Export controller to SolidWorks
    [913535272.sldasm, 913535872.sldasm, 926273088.sldasm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]
2015-03-12 Add Nixie_Driver schematic and PCB
    [Nixie_Driver.PcbDoc, Nixie_Driver.PcbLib, Nixie_Driver.PrjPcb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]
2015-03-14 Finish Nixie_Driver PCB
    [Nixie_Controller.PcbDoc, Nixie_Controller.SchDoc, Nixie_Driver.PcbDoc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]
2015-03-14 Add Nixie_Driver PCB screenshots
2015-03-16 Fix minor bugs in Nixie_Driver
    Change component footprints to M, create new footprint for BT1, add /
    change designators
    [Nixie_Controller.PcbLib, Nixie_Controller.SchLib, Nixie_Driver.PcbDoc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]
2015-04-14 Route power supply
    [Nixie_Driver.PcbDoc, Nixie_Driver.PrjPcb, Nixie_Embedded_Supply.SchDoc]
2015-04-15 Amend repo with Nixie_Supply libs
    [Nixie_Supply.PcbLib, Nixie_Supply.SchLib]
2015-04-15 Finish Nixie_Driver PCB ver 1
    [Nixie_Controller.PcbLib, Nixie_Controller.SchLib, Nixie_Driver.PcbDoc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]
2015-04-29 Cleanup nixie/electronic
    [Nixie_Controller.PcbDoc, Nixie_Controller.PrjPcb]
2015-04-29 Rev 1.0: prepare for production and add docs
    [BOM.xlsx, Nixie_Controller.PcbLib, Nixie_Driver.PcbDoc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]
2015-05-16 Advance Nixie_Driver to Rev 2.0
    Add HT sense, buzzer, some resistors and capacitors, LEDs and a
    push-button
    Fix placement of tubes and programming header, hole size
    Change some footprints to SMD and board shape to rounded rectangle
    [Nixie_Controller.PcbLib, Nixie_Controller.SchLib, Nixie_Driver.PcbLib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]
2015-05-22 MCUtest initial commit
    Supports LEDs and encoder
2015-05-24 Add firmware I2C support
    Waveforms look good on the scope, not yet tested with RTC
2015-06-17 Add hardware I2C support
2015-06-17 Delegate display multiplexing to Timer2
    Clock starts blank. When encoder is moved, a number is shown and
    inc/decremented.
